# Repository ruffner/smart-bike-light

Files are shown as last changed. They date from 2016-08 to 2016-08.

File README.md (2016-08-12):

# smart-bike-light
Motion sensing bike light that automatically turns itself off.

Featuring an integrated SparkFun femtobuck constant current driver, seen in the upper left of the schematic, below.

A work in progress, waiting on the new analog accel board to be printed:

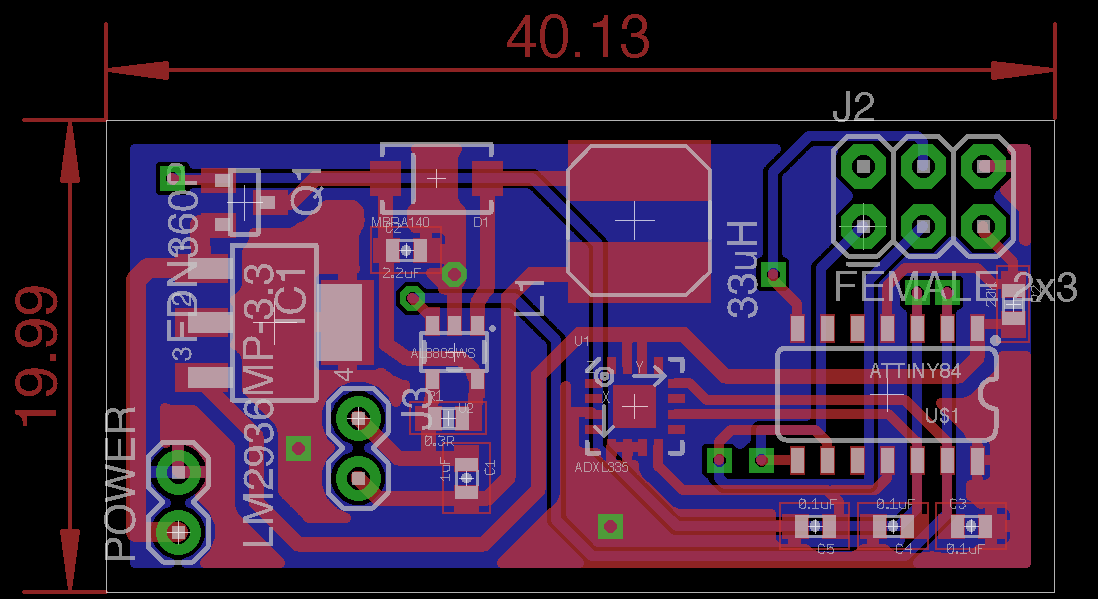
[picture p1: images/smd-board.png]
smd-board


The corresponding schematic:

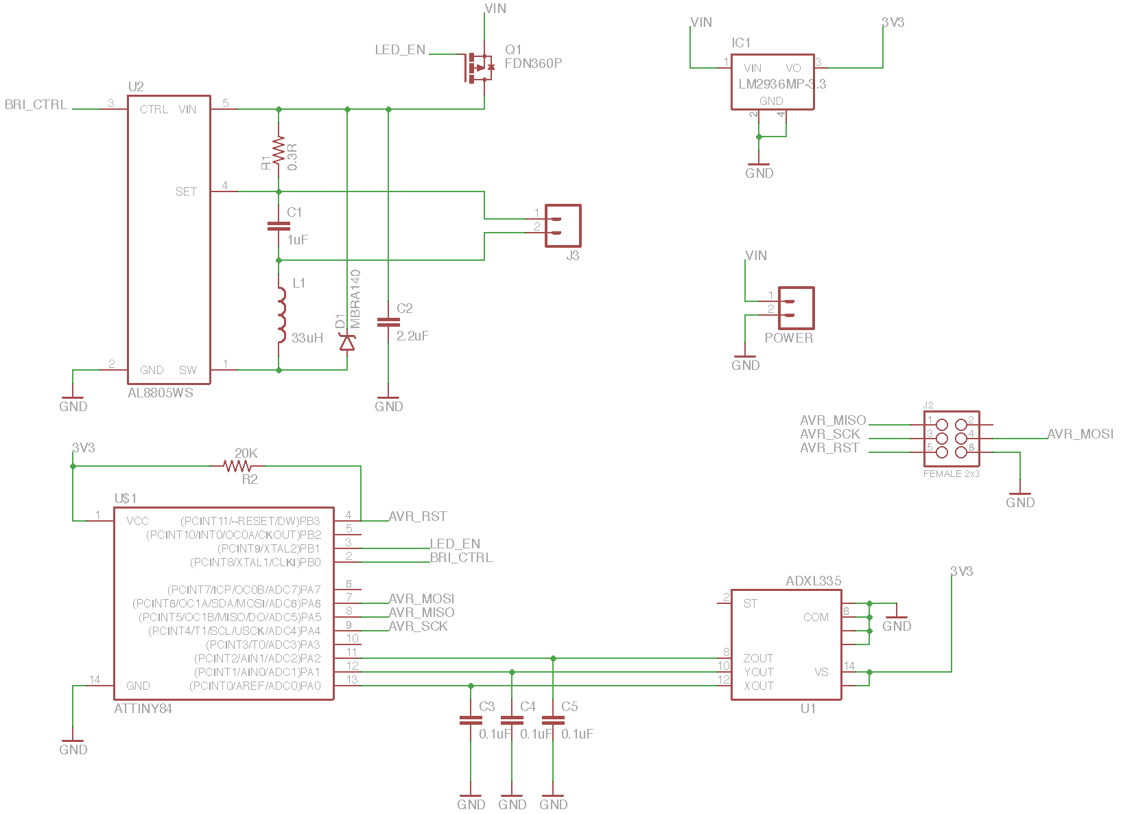
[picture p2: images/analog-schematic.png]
analog-sch


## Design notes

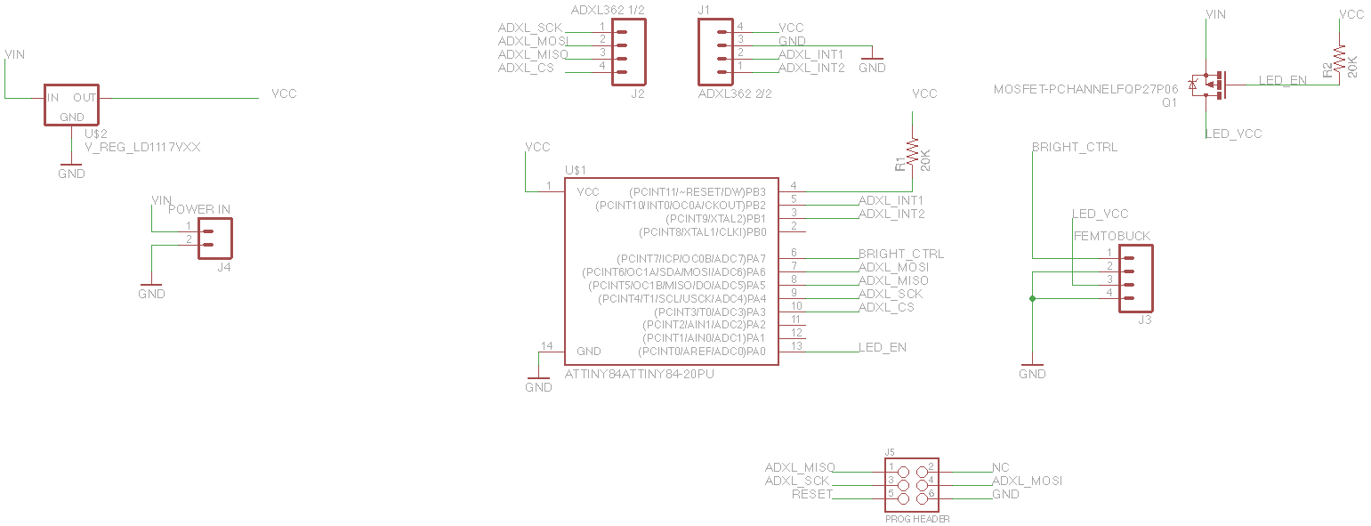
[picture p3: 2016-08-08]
images/prototype_schematic.png

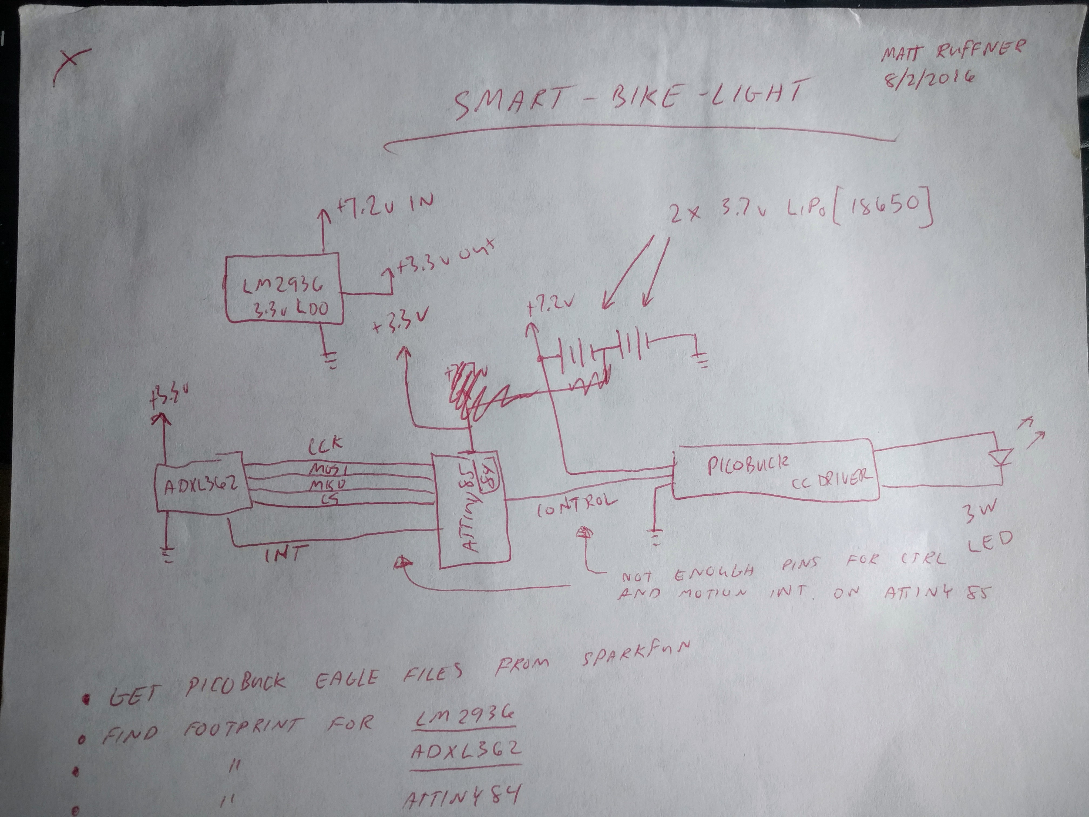
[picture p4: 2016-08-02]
images/plan.jpg

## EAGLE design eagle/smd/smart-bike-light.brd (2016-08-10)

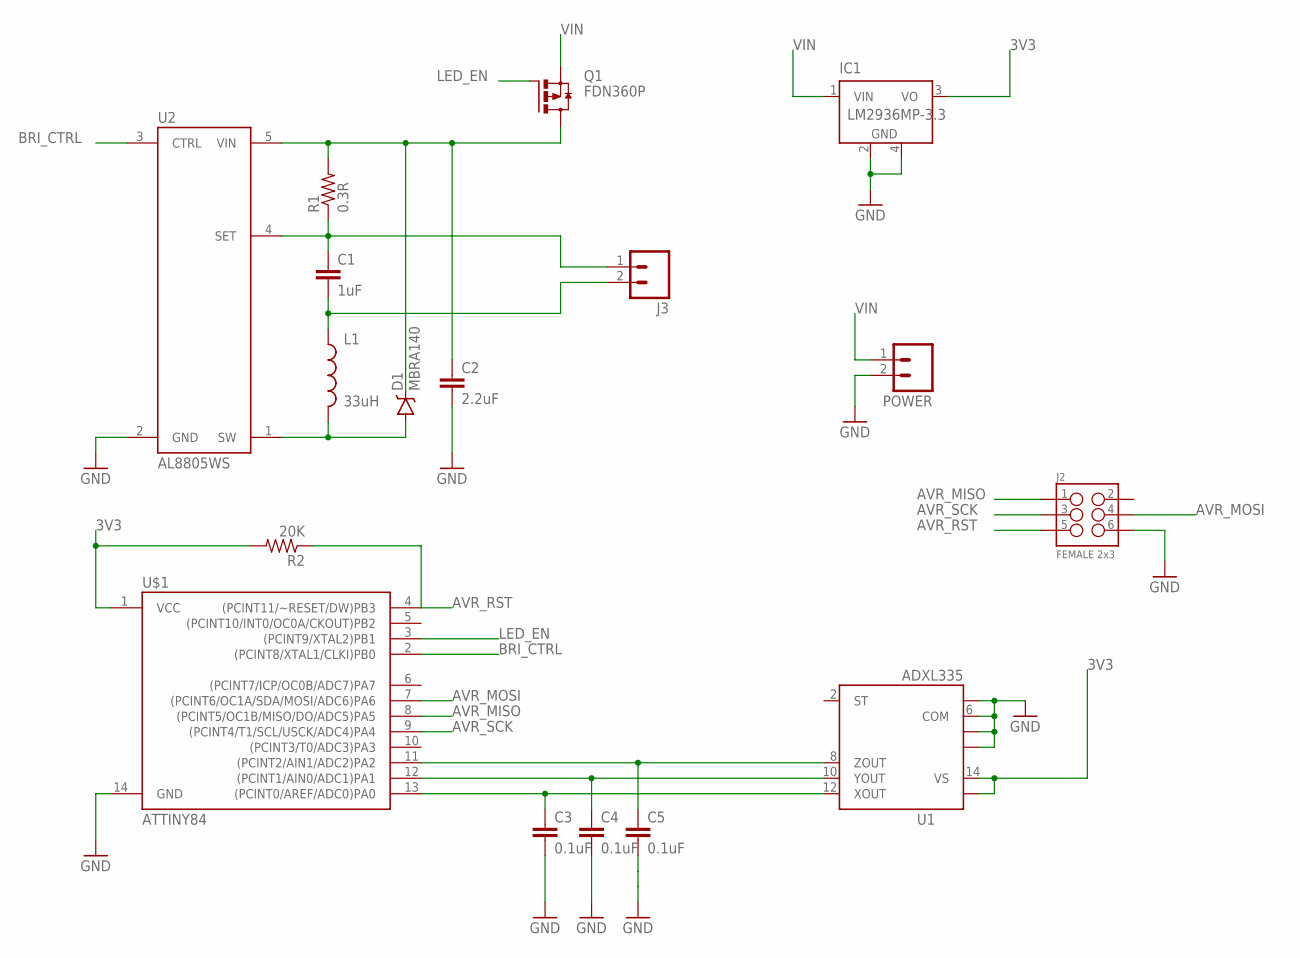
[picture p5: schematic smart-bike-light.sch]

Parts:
C1: 1uF; 0603-CAP
C2: 2.2uF; 0603-CAP
C3, C4, C5: 0.1uF; 0603-CAP
D1: MBRA140; SMA-DIODE
IC1: LM2936MP-3.3; SOT223
J2: FEMALE 2x3; 2X3
J3: M02PTH; 1X02
L1: 33uH; SRN6045
POWER: M02PTH; 1X02
Q1: FDN360P; SUPER-SOT3
R1: 0.3R; 0603-RES
R2: 20K; 0603-RES
U1: ADXL335; LFCSP-16
U2: AL8805WS; SOT23-5
U$1: ATTINY84; SO14

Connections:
3V3: IC1.3 (VO), R2.2, U1.14 (VS), U1.15 (VS), U$1.1 (VCC)
AVR_MISO: J2.1, U$1.8 ((PCINT5/OC1B/MISO/DO/ADC5)PA5)
AVR_MOSI: J2.4, U$1.7 ((PCINT6/OC1A/SDA/MOSI/ADC6)PA6)
AVR_RST: J2.5, R2.1, U$1.4 ((PCINT11/~RESET/DW)PB3)
AVR_SCK: J2.3, U$1.9 ((PCINT4/T1/SCL/USCK/ADC4)PA4)
BRI_CTRL: U2.3 (CTRL), U$1.2 ((PCINT8/XTAL1/CLKI)PB0)
GND: C2.2, C3.2, C4.2, C5.2, IC1.2 (GND), IC1.4 (GND), J2.6, POWER.2, U1.3 (COM), U1.5 (COM), U1.6 (COM), U1.7 (COM), U2.2 (GND), U$1.14 (GND)
LED_EN: Q1.1 (G), U$1.3 ((PCINT9/XTAL2)PB1)
unnamed: C1.1, J3.1, R1.1, U2.4 (SET)
unnamed: C2.1, D1.C, Q1.3 (D), R1.2, U2.5 (VIN)
unnamed: D1.A, L1.2, U2.1 (SW)
unnamed: C1.2, J3.2, L1.1
unnamed: C3.1, U1.12 (XOUT), U$1.13 ((PCINT0/AREF/ADC0)PA0)
unnamed: C4.1, U1.10 (YOUT), U$1.12 ((PCINT1/AIN0/ADC1)PA1)
unnamed: C5.1, U1.8 (ZOUT), U$1.11 ((PCINT2/AIN1/ADC2)PA2)
VIN: IC1.1 (VIN), POWER.1, Q1.2 (S)

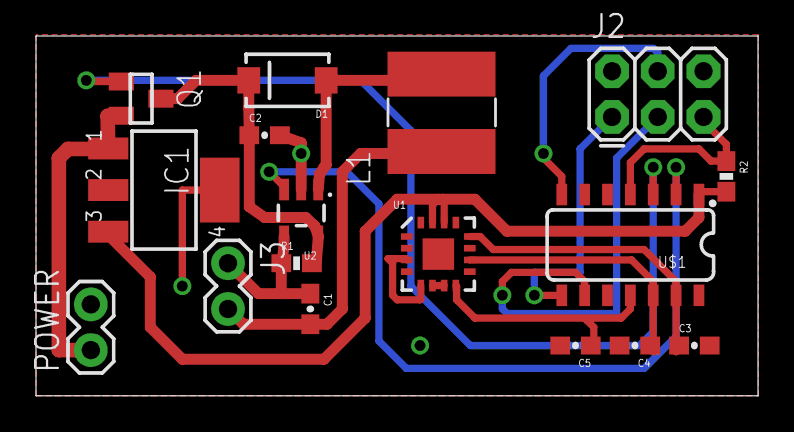
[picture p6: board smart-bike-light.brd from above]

Board: 2 copper layers, 40.1 x 20.0 mm, 17 parts (0 on the bottom side), 16 nets.

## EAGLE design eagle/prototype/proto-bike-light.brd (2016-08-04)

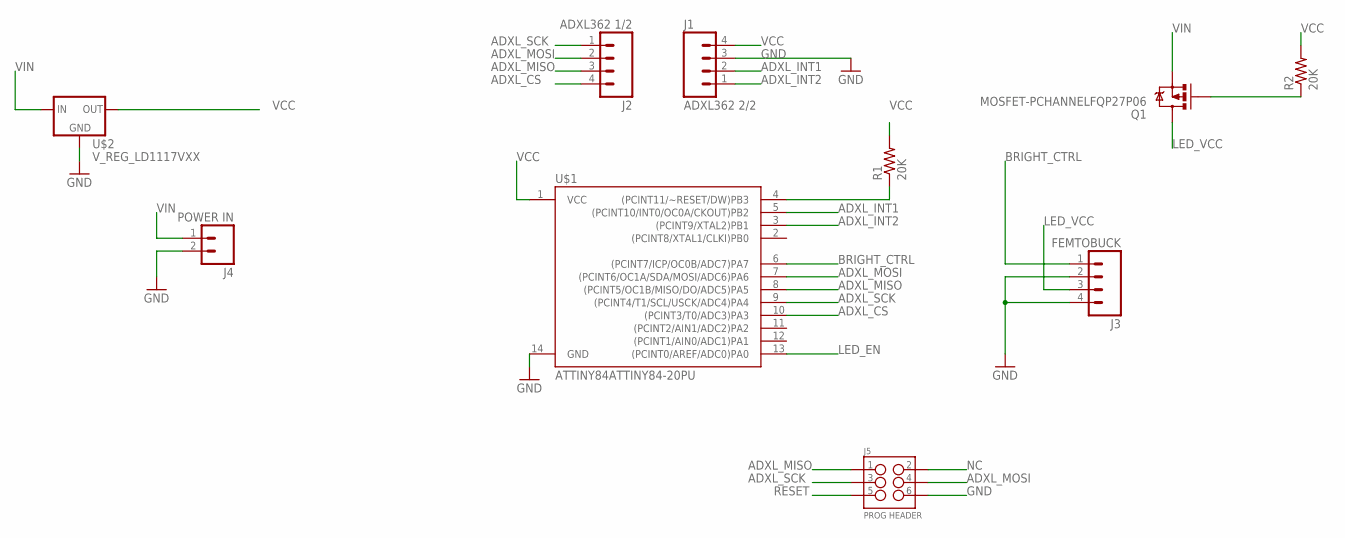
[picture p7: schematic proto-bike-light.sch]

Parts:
J1: ADXL362 2/2; 1X04
J2: ADXL362 1/2; 1X04
J3: FEMTOBUCK; 1X04
J4: POWER IN; 1X02
J5: PROG HEADER; 2X3
Q1: MOSFET-PCHANNELFQP27P06; TO220V
R1, R2: 20K; AXIAL-0.4
U$1: ATTINY84ATTINY84-20PU; DIL14
U$2: V_REG_LD1117VXX; 78XXL

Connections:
ADXL_CS: J2.4, U$1.10 ((PCINT3/T0/ADC3)PA3)
ADXL_INT1: J1.2, U$1.5 ((PCINT10/INT0/OC0A/CKOUT)PB2)
ADXL_INT2: J1.1, U$1.3 ((PCINT9/XTAL2)PB1)
ADXL_MISO: J2.3, J5.1, U$1.8 ((PCINT5/OC1B/MISO/DO/ADC5)PA5)
ADXL_MOSI: J2.2, J5.4, U$1.7 ((PCINT6/OC1A/SDA/MOSI/ADC6)PA6)
ADXL_SCK: J2.1, J5.3, U$1.9 ((PCINT4/T1/SCL/USCK/ADC4)PA4)
BRIGHT_CTRL: J3.1, U$1.6 ((PCINT7/ICP/OC0B/ADC7)PA7)
GND: J1.3, J3.2, J3.4, J4.2, J5.6, U$1.14 (GND), U$2.IN (GND)
LED_EN: Q1.1 (G), R2.P$1 (1), U$1.13 ((PCINT0/AREF/ADC0)PA0)
LED_VCC: J3.3, Q1.2 (D)
NC: J5.2
RESET: J5.5, R1.P$1 (1), U$1.4 ((PCINT11/~RESET/DW)PB3)
VCC: J1.4, R1.P$2 (2), R2.P$2 (2), U$1.1 (VCC), U$2.GND (OUT)
VIN: J4.1, Q1.3 (S), U$2.OUT (IN)

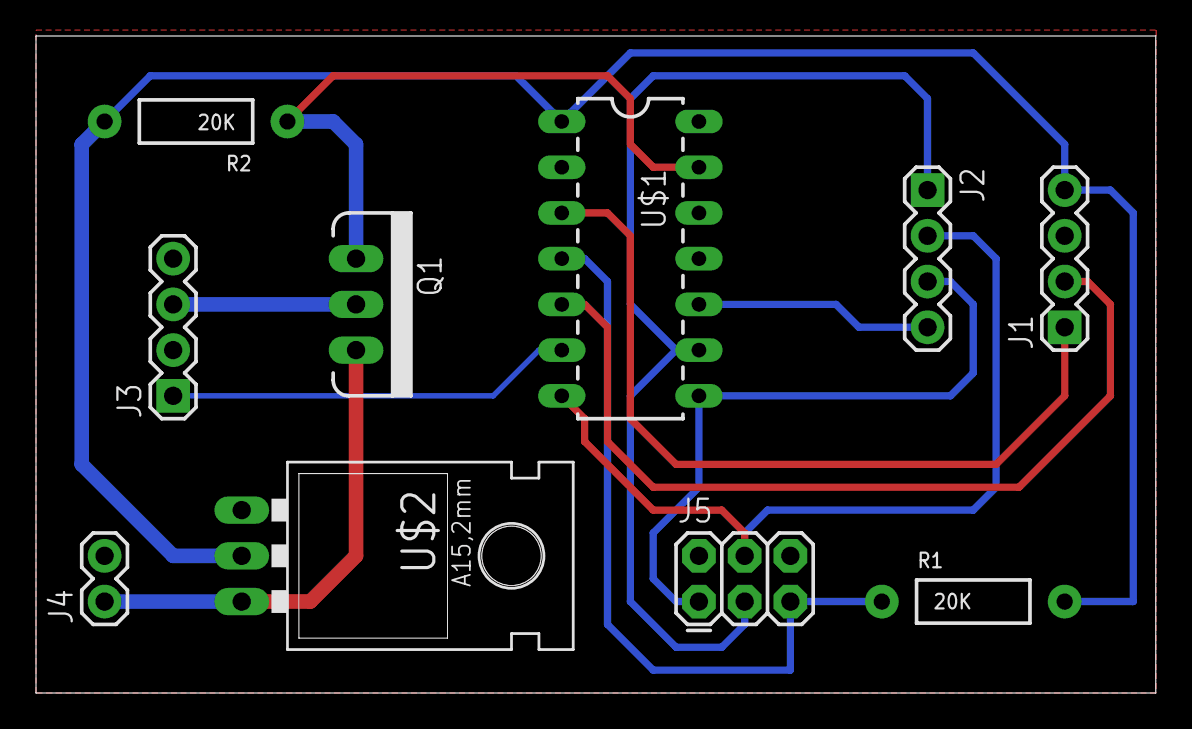
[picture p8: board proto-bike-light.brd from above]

Board: 2 copper layers, 62.2 x 36.5 mm, 10 parts (0 on the bottom side), 13 nets.

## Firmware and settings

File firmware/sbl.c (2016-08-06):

#include <util/delay.h>
#include <avr/io.h> 
#include <inttypes.h>
#include <avr/interrupt.h>

#include "adxl362.h"

void init_accel();
void init_ints();

#define TEST_LED_ON  PORTA |= (1 << PA7)
#define TEST_LED_OFF PORTA &= ~(1 << PA7)

int main()
{
  // set up motion interrupts
  init_accel();

  // set up our interrupts
  //  init_ints();

  DDRA |= (1 << PA7); // config test led as output
  TEST_LED_ON;
  _delay_ms(300);
  TEST_LED_OFF;
  _delay_ms(200);
  TEST_LED_ON;
  _delay_ms(300);
  TEST_LED_OFF;

  //sei();

  while ( 42 ){
    _delay_ms(1000);
    int8_t x_val = read_axis(X);

    
    for ( ;x_val > 0; x_val-- ){
      PORTA ^= (1 << PA7);
      _delay_ms(200);

      PORTA ^= (1 << PA7);
      _delay_ms(200);

    }

  }
  
  return 0;
}

ISR( EXT_INT0_vect )
{
  TEST_LED_ON;
}

ISR( PCINT1_vect )
{
  TEST_LED_OFF;
}

void init_ints()
{
  // rising edge of INT0 pin, activity detection
  MCUCR |= (1 << ISC01) | (1 << ISC00);

  // INT0 and pin change interrupt enable
  GIMSK |= (1 << INT0) | (1 << PCIE1);

  PCMSK1 |= (1 << PCINT9);
}

void init_accel()
{
  
  adxl362_begin();
  config_measure_mode(MODE_MEASURE);

  
  /*config_odr(ODR_12_5_HZ);

  config_linkloop(LINKLOOP_LOOP);

  config_int1( 1 << ACT, 0, 0 );
  
  config_int2( 1 << INACT, 0, 0 );

  config_act_int(1000, 13); // roughly a seconds worth of 1g

  config_inact_int(300, 45); // roughly three seconds worth of stillness
  */
}

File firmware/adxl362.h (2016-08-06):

/*
AVR library for the Analog Devices ADXL362 
ultra low power 3 axis accelerometer
Written for attiny device's USI

Matt Ruffner 2014
 */

#ifndef ADXL362_H
#define ADXL362_H

#include <avr/io.h>
#include <inttypes.h>


//////////////////////
// funtion definitions
//////////////////////

// preliminary
void adxl362_begin();

// measurement
void read_all_axes(int16_t * data);
void read_all_axes_short(int8_t * data);
int16_t read_axis(int axis);
int8_t read_axis_short(int axis);
int16_t read_temp();

// configuration
void config_linkloop(uint8_t mode);
void config_measure_mode(uint8_t mode); // requried call after reset
void config_range(uint8_t range);
void config_odr(uint8_t odr);
void config_int1(uint8_t int_source, uint8_t direction, uint8_t pullup);
void config_int2(uint8_t int_source, uint8_t direction, uint8_t pullup);
void config_act_int(uint16_t thresh, uint8_t time);
void config_inact_int(uint16_t thresh, uint16_t time);

// basic io
uint8_t read_reg(uint8_t reg);
uint16_t read_reg16(uint8_t reg);
void read_fifo(uint8_t * data, uint16_t len);
void write_reg(uint8_t reg, uint8_t value);
void write_reg16(uint8_t reg, uint16_t value);
uint8_t usi_transfer(uint8_t data);


// USI pin definitions
#define ADXL_DDR     DDRA
#define ADXL_PORT    PORTA
#define ADXL_MOSI    PA5
#define ADXL_MISO    PA6
#define ADXL_SCK     PA4
#define ADXL_CS      PA3
#define ADXL_CS_HIGH ADXL_PORT |= (1 << ADXL_CS)
#define ADXL_CS_LOW  ADXL_PORT &= ~(1 << ADXL_CS)

// interrupt pin definitions if ya want em
#define ADXL362_INT1_DDR  DDRB
#define ADXL362_INT1_PORT PORTB
#define ADXL362_INT1_PIN  PINB
#define ADXL362_INT2_DDR  DDRB
#define ADXL362_INT2_PORT PORTB
#define ADXL362_INT2_PIN  PINB
#define ADXL362_INT1      PB2
#define ADXL362_INT2      PB1

// axis definitions for read functions
#define X 0
#define Y 1
#define Z 2

///////////////////////////////
// ADXL362 register definitions
///////////////////////////////

// spi commands
#define ADXL362_WRITE_REGISTER 0x0A
#define ADXL362_READ_REGISTER  0x0B
#define ADXL362_READ_FIFO      0x0D

// identification registers, will always read the same
#define DEVID_AD    0x00
#define DEVID_MST   0x01
#define PARTID      0x02
#define REVID       0x03

// 8 bit resolution, power saving, registers
#define XDATA       0x08
#define YDATA       0x09
#define ZDATA       0x0A

// 12 bit, full resolution, sign extended data registers
// therefor the 4 MSBs of the _H register are all the same 
// and contain the sign of the reading
#define XDATA_L  0x0E
#define XDATA_H  0x0F
#define YDATA_L  0x10
#define YDATA_H  0x11
#define ZDATA_L  0x12
#define ZDATA_H  0x13

// 12 bit sign extended temperature registers
#define TEMP_L 0x14
#define TEMP_H 0x15

// status register
#define ADXL_STATUS          0x0B
#define ERR_USER_REGS   7
#define AWAKE           6
#define INACT           5
#define ACT             4
#define FIFO_OVERRUN    3
#define FIFO_WATERMARK  2
#define FIFO_READY      1
#define DATA_READY      0

// soft reset register, write 0x52, 'R' in ascii, to reset the devce
#define SOFT_RESET 0x1F

// FIFO entries register, the 10 bit number representing the
//  how many valid data samples are int the FIFO buffer
#define FIFO_ENTRIES_L  0x0C
#define FIFO_ENTRIES_H  0x0D

// activity threshold registers
// 11 bit, unsigned value to be compared with the 12 bit
// signed acceleration value
#define THRESH_ACT_L 0x20
#define THRESH_ACT_H 0x21

// activity time register, when used, the duration of motion 
// must be sustained for this amount of time to trigger activity
// detection caclulated by actual time = TIME_ACT/ODR
#define TIME_ACT 0x22

// inactivity threshold registers
// 11 bit unsigned value to be compared to the magnitude of the 
// acceleration value
#define THRESH_INACT_L 0x23
#define THRESH_INACT_H 0x24

// inactivity time registers, a 16 bit value
// actual time = TIME_INACT/ODR, a maximum of almost 90 minutes
#define TIME_INACT_L 0x25
#define TIME_INACT_H 0x26

// (in)activity control register
#define ACT_INACT_CTL 0x27
#define LINKLOOP   4 // 2 bit value
#define INACT_REF  3
#define INACT_EN   2
#define ACT_REF    1
#define ACT_EN     0

#define LINKLOOP_DEFAULT 0
#define LINKLOOP_LINKED  1
#define LINKLOOP_LOOP    2

// FIFO control register
#define FIFO_CONTROL 0x28
#define AH        3
#define FIFO_TEMP 2
#define FIFO_MODE 0 // 2 bit value

// FIFO samples register
// MSbit is AH in FIFO_CONTROL
#define FIFO_SAMPLES 0x29 // defaults to 0x80

// INT1/INT2 function map registers
#define INTMAP1 0x2A
#define INTMAP2 0x2B
#define INT_LOW        7
#define AWAKE          6 
#define INACT          5 
#define ACT            4
#define FIFO_OVERRUN   3
#define FIFO_WATERMARK 2
#define FIFO_READY     1
#define DATA_READY     0

// filter control register
#define FILTER_CTL 0x2C
#define RANGE      6    // 2 bit value
#define HALF_BW    4
#define EXT_SAMPLE 3
#define ODR        0    // 3 bit value

#define RANGE_2G 0
#define RANGE_4G 1
#define RANGE_8G 2

#define ODR_12_5_HZ 0
#define ODR_25_HZ   1
#define ODR_50_HZ   2
#define ODR_100_HZ  3 // reset default
#define ODR_200_HZ  4
#define ODR_400_HZ  5

// power control register
#define POWER_CTL 0x2D
#define EXT_CLK   6
#define LOW_NOISE 4     // 2 bit value
#define WAKEUP    3
#define AUTOSLEEP 2
#define MEASURE   0     // 2 bit value

#define MODE_STANDBY 0 // reset default
#define MODE_MEASURE 2

// self test register
#define SELF_TEST 0x2E
#define ST 0

#endif

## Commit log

2016-08-02 added planned schematic
2016-08-03 added work on schematic and board design.
    [smart-bike-light.brd, smart-bike-light.sch]
2016-08-04 added prototype board with through hole components, programming header and no led driver
    [proto-bike-light.brd, proto-bike-light.sch, smart-bike-light.brd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]
2016-08-06 updated adxl362 pin pin definitions, testing accel communication.
2016-08-08 added prototype schematic for coding reference.
2016-08-10 switched to analog accel
    [smart-bike-light.brd, smart-bike-light.sch]
2016-08-10 updated jumper silkscreens, README
    [smart-bike-light.brd, smart-bike-light.sch]

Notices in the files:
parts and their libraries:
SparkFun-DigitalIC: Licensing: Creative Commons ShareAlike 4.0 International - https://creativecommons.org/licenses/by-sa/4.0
